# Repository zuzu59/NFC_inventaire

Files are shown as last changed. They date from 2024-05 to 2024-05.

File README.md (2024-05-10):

# NFC_inventaire
Système pour lire une puce NFC et donner des critères de qualité dans une DB API REST

zf240511.0001

**ATTENTION, documentation en cours de rédaction et le schéma n'est pas encore fait :-(  zf240510.1444**

## Buts
Système pour lire une puce NFC et donner des critères de qualité dans une DB API REST.

## Problématiques
Comme ce système va être utilisé dans une fromagerie pour inventorier des fromages dans une cave d'affinage, l'environnement est très agréssif, de l'eau salée partout et une humidité de 90%

Il faudra que le système soit totalement waterproof à la projection et que l'interface utilisateur soit avec des *boutons* capacitifs hyper simple à utiliser pour envoyer les caractéristiques des fromages dans la DB.

## Moyens
### J'ai utilisé pour ce projet
#### un esp32-c3 super mini
https://grabcad.com/library/esp32-c3-supermini-1

https://fr.aliexpress.com/item/1005006170575141.html

https://www.studiopieters.nl/esp32-c3-pinout/

https://forum.fritzing.org/t/need-esp32-c3-super-mini-board-model/20561

#### Un lecteur de puces NFC
https://www.aliexpress.com/item/1005006005040320.html

https://randomnerdtutorials.com/security-access-using-mfrc522-rfid-reader-with-arduino/

https://www.instructables.com/Using-Mifare-Ultralight-C-With-RC522-on-Arduino/

https://www.arduino.cc/reference/en/libraries/mfrc522/

https://forum.fritzing.org/uploads/default/original/2X/3/3bd6227b905a571e0d28ae941e6b9554a32d2a9a.fzpz

https://github.com/miguelbalboa/rfid/tree/master/doc/fritzing

#### Un interrupteur analogique
https://www.aliexpress.com/item/1005003404607069.html

#### Des switches capacitifs
https://www.aliexpress.com/item/1005006087171183.html

## Sources
https://forum.fritzing.org/t/need-esp32-c3-super-mini-board-model/20561

https://www.digikey.fr/fr/resources/conversion-calculators/conversion-calculator-voltage-divider

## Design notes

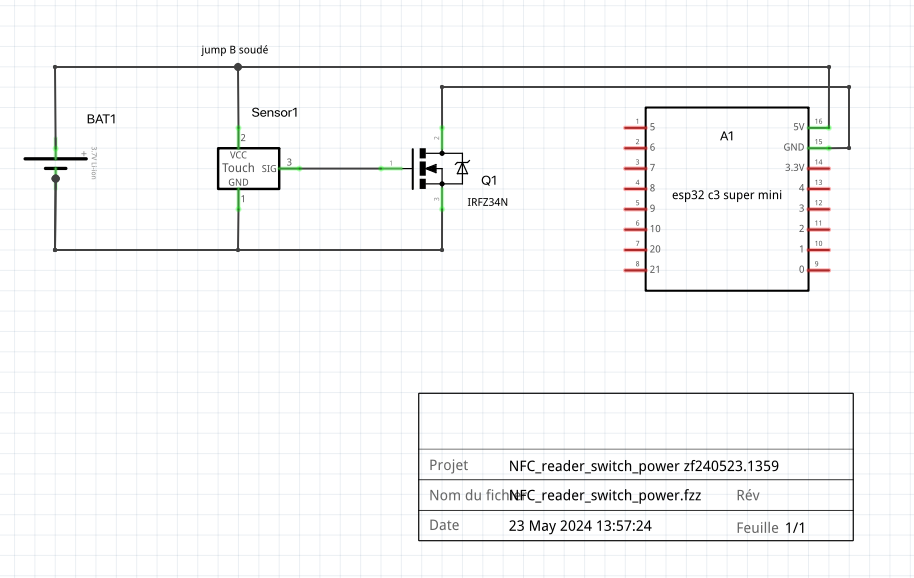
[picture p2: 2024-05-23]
schema/schema_NFC_reader_switch_power.png

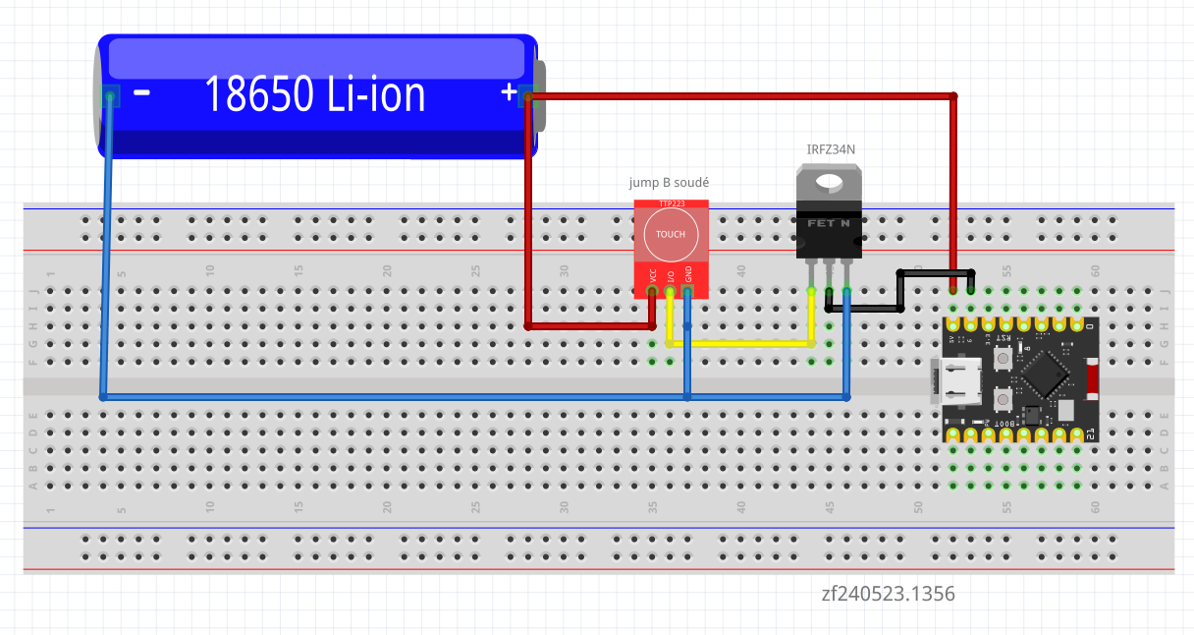
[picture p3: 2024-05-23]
schema/breadboard_NFC_reader_switch_power.png

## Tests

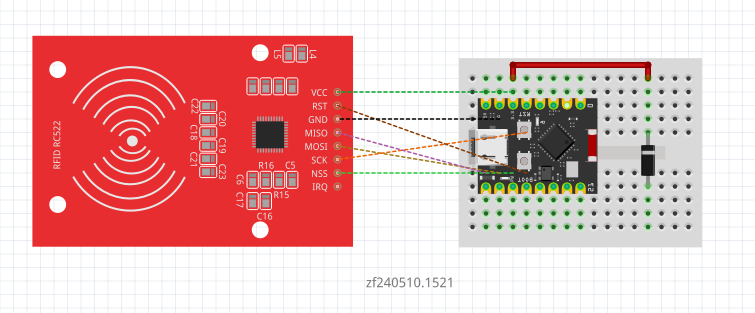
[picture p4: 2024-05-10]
schema/breadboard_NFC_reader_test1.png

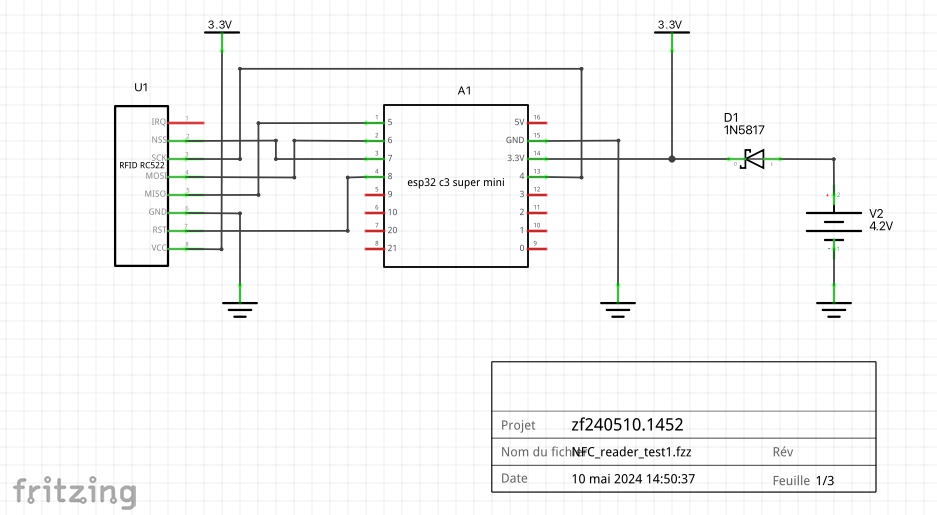
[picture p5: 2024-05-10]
schema/schema NFC_reader_test1.png

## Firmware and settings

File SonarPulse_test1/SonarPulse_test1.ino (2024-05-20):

// Petit test pour voir comment faire un sonar pulse avec la led sans bloquer la boucle loop
// ATTENTION, ce code a été écrit pour un esp32-c3 super mini. Pas testé sur les autres boards !
//
#define zVERSION "zf240520.1320"
/*
Utilisation:

Astuce:

Installation:

Pour les esp32-c3 super mini, il faut:
 * choisir comme board ESP32C3 Dev Module
 * disabled USB CDC On Boot et utiliser USBSerial. au lieu de Serial. pour la console !
 * changer le schéma de la partition à Minimal SPIFFS (1.9MB APP with OTA/190kB SPIFFS)

Pour le WiFiManager, il faut installer cette lib depuis le lib manager sur Arduino:
https://github.com/tzapu/WiFiManager

Pour le lecteur de NFC RFID RC522, il faut installer cette lib depuis le lib manager sur Arduino:
https://github.com/miguelbalboa/rfid   (elle est vieille mais fonctionne encore super bien zf240510)

Pour JSON, il faut installer cette lib:
https://github.com/bblanchon/ArduinoJson

Pour le stick LED RGB il faut installer cette lib: 
https://github.com/FastLED/FastLED    (by Daniel Garcia)

Sources:
https://randomnerdtutorials.com/security-access-using-mfrc522-rfid-reader-with-arduino/
https://forum.fritzing.org/t/need-esp32-c3-super-mini-board-model/20561
https://www.aliexpress.com/item/1005006005040320.html
https://randomnerdtutorials.com/esp32-useful-wi-fi-functions-arduino
https://dronebotworkshop.com/wifimanager/
https://github.com/FastLED/FastLED/blob/master/examples/Blink/Blink.ino
https://lastminuteengineers.com/esp32-ota-web-updater-arduino-ide/
https://chat.mistral.ai/    pour toute la partie API REST ᕗ
*/

/*
 * 
 * Pin layout used:
 * -----------------------------------------------------------------------------------------
 *             MFRC522      ESP32-c3
 *             Reader/PCB   super mini
 * Signal      Pin          Pin
 * -----------------------------------------------------------------------------------------
 * RST/Reset   RST          GPIO10
 * SPI SS      SDA(SS)      GPIO7
 * SPI MOSI    MOSI         GPIO6
 * SPI MISO    MISO         GPIO5
 * SPI SCK     SCK          GPIO4
 *
 */


// #define DEBUG true
// #undef DEBUG


// General
const int ledPin = 8;    // the number of the LED pin
const int buttonPin = 9;  // the number of the pushbutton pin
float rrsiLevel = 0;      // variable to store the RRSI level
const int zSonarPulseOn = 100;    // délai pour sonarPulse
const int zSonarPulseOff = 200;    // délai pour sonarPulse
const int zSonarPulseWait = 1000;    // délai pour sonarPulse
byte zSonarPulseState = 1;    // état pour sonarPulse
long zSonarPulseNextMillis = 0;    // état pour sonarPulse

String newRFID = "00 00 00 00 00 00 00";
String tagFromager = "";
String tagNotation = "";

bool zProcFromager = false;
bool zProcAddFromage = false;
bool zProcAddInventaire = false;
bool zProcAddTagCmd = false;
bool zProcNotation = false;

const int ledWifi               = 0;
const int ledProcFromager       = 1;
const int ledProcAddFromage     = 2;
const int ledProcAddInventaire  = 3;
const int ledProcAddTagCmd      = 4;
const int ledProcNotation       = 5;
const int ledOk                 = 6;
const int ledFree               = 7;





// WIFI
#include <WiFi.h>
#include <HTTPClient.h>
#include <WiFiManager.h>
#include "secrets.h"
WiFiClient client;
HTTPClient http;

static void ConnectWiFi() {
    WiFi.mode(WIFI_STA); //Optional    
    WiFiManager wm;
    bool res;
    res = wm.autoConnect("esp32_wifi_config",""); // password protected ap
    if(!res) {
        USBSerial.println("Failed to connect");
        // ESP.restart();
    }
    WiFi.setTxPower(WIFI_POWER_8_5dBm);  //c'est pour le Lolin esp32-c3 mini V1 ! https://www.wemos.cc/en/latest/c3/c3_mini_1_0_0.html
    int txPower = WiFi.getTxPower();
    USBSerial.print("TX power: ");
    USBSerial.println(txPower);
    USBSerial.println("Connecting");
    while(WiFi.status() != WL_CONNECTED){
        USBSerial.print(".");
        delay(100);
    }
    USBSerial.println("\nConnected to the WiFi network");
    USBSerial.print("SSID: ");
    USBSerial.println(WiFi.SSID());
    USBSerial.print("RSSI: ");
    USBSerial.println(WiFi.RSSI());
    USBSerial.print("IP: ");
    USBSerial.println(WiFi.localIP());
}


// OTA WEB server
const char* host = "esp32-c3";
#include "otaWebServer.h"


// Stick LED RGB
#include <FastLED.h>
#define NUM_LEDS 8
#define DATA_PIN 3
CRGB leds[NUM_LEDS];


// API JSON
#include <ArduinoJson.h>
const char* zToken = apiToken;
long zIndex = 0;

const char* apiGetIndexToto = apiServerName "/api/v2/tables/mccwrj43jwtogvs/records?viewId=vwwm6yz0uhytc9er&fields=Index&sort=-Index&limit=1&shuffle=0&offset=0";
const char* apiPostNewRecordToto = apiServerName "/api/v2/tables/mccwrj43jwtogvs/records";

const char* apiGetIndexTagCmd = apiServerName "/api/v2/tables/mmkk01cafw4ynyp/records?viewId=vw68oujklglmmlp3&fields=Index&sort=-Index&limit=1&shuffle=0&offset=0";
const char* apiPostNewRecordTagCmd = apiServerName "/api/v2/tables/mmkk01cafw4ynyp/records";

const char* apiGetRfidTagCmd = apiServerName "/api/v2/tables/mmkk01cafw4ynyp/records?viewId=vw68oujklglmmlp3&fields=UID%20RFID&limit=25&shuffle=0&offset=0";

const char* apiGetIndexTagLog = apiServerName "/api/v2/tables/md736jl0ppzh1jj/records?viewId=vwl66xl4gwk919f1&fields=Index&sort=-Index&limit=1&shuffle=0&offset=0";
const char* apiPostNewRecordTagLog = apiServerName "/api/v2/tables/md736jl0ppzh1jj/records";


String getToDB(String zApigetToDB) {
  // Efectue la requête GET pour récupérer l'enregistrement
  http.begin(zApigetToDB);
  http.addHeader("accept", "application/json");
  http.addHeader("xc-token", zToken);
  int httpCode = http.GET();
  if (httpCode > 0) {
    if (httpCode == HTTP_CODE_OK) {
      String payload = http.getString();
      USBSerial.println(payload);
      http.end();
      return(payload);
    } else {
      USBSerial.printf("Error on HTTP request: %d\n", httpCode);
    }
  } else {
    USBSerial.println("Error on HTTP request");
  }
  http.end();
}


void getIndex(String payload){
  // Alloue un objet DynamicJsonDocument pour stocker le JSON
  DynamicJsonDocument doc(1024);
  // Désérialise le JSON
  DeserializationError error = deserializeJson(doc, payload);
  if (error) {
    USBSerial.print("deserializeJson() failed: ");
    USBSerial.println(error.f_str());
    return;
  }
  // Récupère le champ "Index" et l'incrémente
  zIndex = doc["list"][0]["Index"].as<long>() + 1;
  USBSerial.print("Index incremented: ");
  USBSerial.println(zIndex);
}




static void postToDB(String zApiPostToDb, String jsonReqBody) {
  // Effectuer la requête POST pour créer le nouvel enregistrement
  http.begin(zApiPostToDb);
  http.addHeader("Content-Type", "application/json");
  http.addHeader("xc-token", zToken);
  int httpCode = http.POST(jsonReqBody);
  if (httpCode > 0) {
    USBSerial.printf("POST request response code: %d\n", httpCode);
    if (httpCode == HTTP_CODE_OK) {
      String response = http.getString();
      USBSerial.println("POST request response:");
      USBSerial.println(response);
    }
  } else {
    USBSerial.println("Error on POST request");
  }
  http.end();
}






// RFID MFRC522
#include <SPI.h>
#include <MFRC522.h>

#define SS_PIN 7
#define RST_PIN 10
 
MFRC522 rfid(SS_PIN, RST_PIN);  // Instance of the class
MFRC522::MIFARE_Key key; 

// Init array that will store new NUID 
byte nuidPICC[7];

// start RFID
void startRFID() {
  SPI.begin(); // Init SPI bus
  rfid.PCD_Init(); // Init MFRC522 

  for (byte i = 0; i < 6; i++) {
    key.keyByte[i] = 0xFF;
  }

  USBSerial.println("Prêt à scanner les tags NFC ᕗ");
}


// Lit un tag NFC 
int readRFID() {
  if (rfid.PICC_IsNewCardPresent()){
    USBSerial.println("Une carte est présente !");
    // Verify if the NUID has been readed
    if (rfid.PICC_ReadCardSerial()){
      // Halt PICC and Stop encryption on PCD
      rfid.PICC_HaltA(); rfid.PCD_StopCrypto1();
      // Get card type
      USBSerial.print("\n\n*****************\nCarte type: ");
      MFRC522::PICC_Type piccType = rfid.PICC_GetType(rfid.uid.sak);
      USBSerial.println(rfid.PICC_GetTypeName(piccType));
      // New UID ?
      if (rfid.uid.uidByte[0] != nuidPICC[0] || rfid.uid.uidByte[1] != nuidPICC[1] || rfid.uid.uidByte[2] != nuidPICC[2] || 
        rfid.uid.uidByte[3] != nuidPICC[3] || rfid.uid.uidByte[4] != nuidPICC[4] || rfid.uid.uidByte[5] != nuidPICC[5] || 
        rfid.uid.uidByte[6] != nuidPICC[6] ) {
        // Store NUID into nuidPICC array
        for (byte i = 0; i < 7; i++) { nuidPICC[i] = rfid.uid.uidByte[i]; }
        convHex(rfid.uid.uidByte, rfid.uid.size);
        return(1);
      } else {
        return(3);
      }
    }
  }else {
    return(0);
  }
}


// Converti l'UID en hexa dans newRFID
void convHex(byte *buffer, byte bufferSize) {
  newRFID = "";
  for (byte i = 0; i < bufferSize; i++) {
    char hexStr[3]; // Crée un tableau temporaire pour stocker la valeur hexadécimale
    sprintf(hexStr, "%02X", buffer[i]); // Convertit la valeur en hexadécimal et la stocke dans hexStr
    newRFID += hexStr; // Concatène la valeur hexadécimale à newRFID
    newRFID += " "; // Ajoute un espace après chaque octet
  }
  newRFID.trim(); // Supprime les espaces supplémentaires à la fin de la chaîne
}







void setup() {
    pinMode(ledPin, OUTPUT);
    sonarPulse();
    pinMode(buttonPin, INPUT_PULLUP);

    // start serial console
    USBSerial.begin(19200);
    USBSerial.setDebugOutput(true);       //pour voir les messages de debug des libs sur la console série !
    delay(3000);                          //le temps de passer sur la Serial Monitor ;-)
    USBSerial.println("\n\n\n\n**************************************\nCa commence !");
    USBSerial.println(zVERSION);

    // si le bouton FLASH de l'esp32-c3 est appuyé dans les 3 secondes après le boot, la config WIFI sera effacée !
    if ( digitalRead(buttonPin) == LOW) {
      WiFiManager wm;    
      wm.resetSettings();
      USBSerial.println("Config WIFI effacée !"); delay(1000);
      ESP.restart();
    }

    // start LED RGB
    FastLED.addLeds<NEOPIXEL, DATA_PIN>(leds, NUM_LEDS);  // GRB ordering is assumed

    // start WIFI
    leds[ledWifi] = CRGB::Blue; FastLED.show();
    digitalWrite(ledPin, HIGH);
    USBSerial.println("Connect WIFI !");
    ConnectWiFi();
    leds[ledWifi] = CRGB::Green; FastLED.show();
    digitalWrite(ledPin, LOW);
    delay(200); 

    // start OTA server
    otaWebServer();

    // leds[6] = CRGB::Blue; FastLED.show();
    // USBSerial.println("Et en avant pour la connexion à la DB !");
    // USBSerial.print("\nAvec comme apiGetIndex: ");
    // USBSerial.println(apiGetIndex);
    // USBSerial.print("et comme apiPostNewRecord: ");
    // USBSerial.println(apiPostNewRecord);

    // // start API REST
    // sendToDB("C'est le boot il n'y a pas de TAG !", zVERSION);
    // digitalWrite(ledPin, HIGH); delay(200); digitalWrite(ledPin, LOW); delay(200);
    // digitalWrite(ledPin, HIGH); delay(200); digitalWrite(ledPin, LOW); delay(200);
    // digitalWrite(ledPin, HIGH); delay(200); digitalWrite(ledPin, LOW); delay(200);
    // leds[6] = CRGB::Green; FastLED.show();
    // delay(3000); 
    // leds[6] = CRGB::Black; FastLED.show();

    // // start RFID
    // startRFID();

}


void loop() {
  // OTA loop
  server.handleClient();

  // // Lit un tag NFC 
  // leds[ledProcAddFromage] = CRGB::Blue; FastLED.show();
  // int statRFID(readRFID());
  // // USBSerial.println(statRFID);
  // if (statRFID == 1) {
  //   leds[ledProcAddFromage] = CRGB::Green; FastLED.show();
  //   USBSerial.println("Une nouvelle carte est détectée !");
  //   USBSerial.print("L'UID de la carte est: ");
  //   USBSerial.println(newRFID);
  //   procTagLog();
  //   delay(300);
  //   leds[ledProcAddFromage] = CRGB::Blue; FastLED.show();
  // } else if (statRFID == 3) {
  //   leds[ledProcAddFromage] = CRGB::Orange; FastLED.show();
  //   USBSerial.println("Carte déjà lue !");
  //   delay(300);
  //   leds[ledProcAddFromage] = CRGB::Blue; FastLED.show();
  // }


  sonarPulse();
}


void clearAllProcedures(){
  zProcFromager = false;
  zProcAddFromage = false;
  zProcAddInventaire = false;
  zProcAddTagCmd = false;
  zProcNotation = false;
}



void procFromager(){
  USBSerial.println("C'est la procédure procFromager !");
  leds[ledProcFromager] = CRGB::Green; FastLED.show();
  delay(300);
  leds[ledProcFromager] = CRGB::Black; FastLED.show();
}

void procAddFromage(){
  USBSerial.println("C'est la procédure procAddFromage !");
  leds[ledProcAddFromage] = CRGB::Green; FastLED.show();
  delay(300);
  leds[ledProcAddFromage] = CRGB::Black; FastLED.show();
}

void procAddInventaire(){
  USBSerial.println("C'est la procédure procAddInventaire !");
  leds[ledProcAddInventaire] = CRGB::Green; FastLED.show();
  delay(300);
  leds[ledProcAddInventaire] = CRGB::Black; FastLED.show();
}

void procAddTagCmd(){
  USBSerial.println("C'est la procédure procAddTagCmd !");
  leds[ledProcAddTagCmd] = CRGB::Green; FastLED.show();
  delay(300);
  leds[ledProcAddTagCmd] = CRGB::Black; FastLED.show();
}

void procNotation(){
  USBSerial.println("C'est la procédure procNotation !");
  leds[ledProcNotation] = CRGB::Green; FastLED.show();
  delay(300);
  leds[ledProcNotation] = CRGB::Black; FastLED.show();
}

void procTagLog(){
  USBSerial.println("C'est la procédure procTagLog !");

  
  getIndex(getToDB(apiGetIndexTagLog));

  // Créer le corps de la requête POST
  StaticJsonDocument<1024> reqBody;
  reqBody["Index"] = zIndex;
  reqBody["UID RFID"] = newRFID;
  reqBody["Comment"] = zVERSION;
  reqBody["SSID"] = WiFi.SSID();
  reqBody["RSSI"] = WiFi.RSSI();
  reqBody["IP"] = WiFi.localIP();
  String jsonReqBody;
  serializeJson(reqBody, jsonReqBody);

  // Post la requête à la DB
  postToDB(apiPostNewRecordTagLog, jsonReqBody);

  leds[ledOk] = CRGB::Green; FastLED.show();
  delay(300);
  leds[ledOk] = CRGB::Black; FastLED.show();
}


// const int zSonarPulseOn = 25;    // délai pour sonarPulse
// const int zSonarPulseOff = 50;    // délai pour sonarPulse
// const int zSonarPulseWait = 200;    // délai pour sonarPulse
// byte zSonarPulseState = 1;    // état pour sonarPulse 1=allumé On, 2= éteint Off, 3= allumé On, 4= éteint Wait
// long zSonarPulseNextMillis = 0;    // état pour sonarPulse


// Machine à état pour faire pulser deux fois la petite LED sans bloquer le système
void sonarPulse(){
  if (zSonarPulseNextMillis < millis()){
    switch (zSonarPulseState){
      // 1ère pulse allumée que l'on doit éteindre !
      case 1:
        digitalWrite(ledPin, HIGH);
        zSonarPulseNextMillis = millis() + zSonarPulseOff;
        zSonarPulseState = 2;
        break;
      // 1ère pulse éteinte que l'on doit allumer !
      case 2:
        digitalWrite(ledPin, LOW);
        zSonarPulseNextMillis = millis() + zSonarPulseOn;
        zSonarPulseState = 3;
        break;
      // 2e pulse allumée que l'on doit éteindre et attendre le wait !
      case 3:
        digitalWrite(ledPin, HIGH);
        zSonarPulseNextMillis = millis() + zSonarPulseWait;
        zSonarPulseState = 4;
        break;
      // 2e pulse éteinte pendant le wait que l'on doit allumer !
      case 4:
        digitalWrite(ledPin, LOW);
        zSonarPulseNextMillis = millis() + zSonarPulseOn;
        zSonarPulseState = 1;
        break;
    }
  }
}

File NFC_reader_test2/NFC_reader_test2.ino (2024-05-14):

// Tests pour lire l'UID sur une carte NFC avec le lecteur RFID RC522
// ATTENTION, ce code a été écrit pour un esp32-c3 super mini. Pas testé sur les autres boards !
//
#define zVERSION "zf240512.1619"

//
// Utilisation:
//
// Astuce:
//
// Installation:
// 
// Il faut disabled USB CDC On Boot et utiliser USBSerial. au lieu de Serial. pour la console !
//
// Pour le lecteur de NFC RFID RC522, il faut installer cette lib depuis le lib manager sur Arduino:
// https://github.com/miguelbalboa/rfid   (elle est vieille mais fonctionne encore très bien zf240510)
//
// Pour le analog buttons il faut installer ces lib: 
//https://github.com/rlogiacco/AnalogButtons
//
// Sources:
// https://randomnerdtutorials.com/security-access-using-mfrc522-rfid-reader-with-arduino/
// https://forum.fritzing.org/t/need-esp32-c3-super-mini-board-model/20561
// https://www.aliexpress.com/item/1005006005040320.html
// https://randomnerdtutorials.com/esp32-useful-wi-fi-functions-arduino
//
/*
 * 
 * Pin layout used:
 * -----------------------------------------------------------------------------------------
 *             MFRC522      ESP32-c3
 *             Reader/PCB   super mini
 * Signal      Pin          Pin
 * -----------------------------------------------------------------------------------------
 * RST/Reset   RST          GPIO10   ATTENTION changé de 8 à 10 le 240512.1616, car au de la LED BUILTIN
 * SPI SS      SDA(SS)      GPIO7
 * SPI MOSI    MOSI         GPIO6
 * SPI MISO    MISO         GPIO5
 * SPI SCK     SCK          GPIO4
 *
 */


// #define DEBUG true
// #undef DEBUG


// General
const int ledPin = 8;    // the number of the LED pin
//
// ATTENTION, il faudra changer la pin RST pour le lecteur RFID RC522 car elle est utilisée par la led builting zf240512.1246
//
const int buttonPin = 9;  // the number of the pushbutton pin


// RFID MFRC522
#include <SPI.h>
#include <MFRC522.h>

#define SS_PIN 7
#define RST_PIN 10               // ATTENTION changé de 8 à 9 le 240512.1616, car au de la LED BUILTIN
 
MFRC522 rfid(SS_PIN, RST_PIN);  // Instance of the class
MFRC522::MIFARE_Key key; 

// Init array that will store new NUID 
byte nuidPICC[4];


// Helper routine to dump a byte array as hex values to Serial. 
void printHex(byte *buffer, byte bufferSize) {
    for (byte i = 0; i < bufferSize; i++) {
      USBSerial.print(buffer[i] < 0x10 ? " 0" : " ");
      USBSerial.print(buffer[i], HEX);
    }
}


// Helper routine to dump a byte array as dec values to Serial.
void printDec(byte *buffer, byte bufferSize) {
    for (byte i = 0; i < bufferSize; i++) {
      USBSerial.print(' ');
      USBSerial.print(buffer[i], DEC);
    }
}


void setup() { 
    pinMode(ledPin, OUTPUT);
    digitalWrite(ledPin, HIGH); delay(200); digitalWrite(ledPin, LOW); delay(200);
    digitalWrite(ledPin, HIGH); delay(200); digitalWrite(ledPin, LOW); delay(200);


    USBSerial.begin(19200);
    USBSerial.setDebugOutput(true);       //pour voir les messages de debug des libs sur la console série !
    delay(3000);  //le temps de passer sur la Serial Monitor ;-)
    USBSerial.println("\n\n\n\n**************************************\nCa commence !\n");

    SPI.begin(); // Init SPI bus
    rfid.PCD_Init(); // Init MFRC522 

    for (byte i = 0; i < 6; i++) {
      key.keyByte[i] = 0xFF;
    }

    USBSerial.println(F("This code scan ALL MIFARE UID ᕗ"));
    USBSerial.print(F("Using the following key:"));
    printHex(key.keyByte, MFRC522::MF_KEY_SIZE);
}
 
void loop() {

    // Reset the loop if no new card present on the sensor/reader. This saves the entire process when idle.
    if ( ! rfid.PICC_IsNewCardPresent())
      return;

    // Verify if the NUID has been readed
    if ( ! rfid.PICC_ReadCardSerial())
      return;

    digitalWrite(ledPin, HIGH); delay(200); digitalWrite(ledPin, LOW); delay(200);
    digitalWrite(ledPin, HIGH); delay(200); digitalWrite(ledPin, LOW); delay(200);
    digitalWrite(ledPin, HIGH); delay(200); digitalWrite(ledPin, LOW); delay(200);

    USBSerial.print(F("\n\n*****************\nPICC type: "));
    MFRC522::PICC_Type piccType = rfid.PICC_GetType(rfid.uid.sak);
    USBSerial.println(rfid.PICC_GetTypeName(piccType));



    if (rfid.uid.uidByte[0] != nuidPICC[0] || 
      rfid.uid.uidByte[1] != nuidPICC[1] || 
      rfid.uid.uidByte[2] != nuidPICC[2] || 
      rfid.uid.uidByte[3] != nuidPICC[3] ) {
      USBSerial.println(F("A new card has been detected."));

      // Store NUID into nuidPICC array
      for (byte i = 0; i < 4; i++) {
        nuidPICC[i] = rfid.uid.uidByte[i];
      }
    
      USBSerial.println(F("The NUID tag is:"));
      USBSerial.print(F("In hex: "));
      printHex(rfid.uid.uidByte, rfid.uid.size);
      USBSerial.println();
      USBSerial.print(F("In dec: "));
      printDec(rfid.uid.uidByte, rfid.uid.size);
      USBSerial.println();
    }
    else USBSerial.println(F("Card read previously."));

    // Halt PICC
    rfid.PICC_HaltA();

    // Stop encryption on PCD
    rfid.PCD_StopCrypto1();
}

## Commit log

2024-05-10 new: YEAH, on dirait que je suis capable de lire l'UID d'une carte NFC NTAG215 presque du 1er coup \o/
    [thermo-int-mqtt-dsleep.fzz]
2024-05-10 new: fait enfin le schéma de câblage du RFID RC522 reader. Très important car il n'est pas facile (5 câbles)
    [NFC_reader_test1.fzz]
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2024-05-11 new: commencé de faire des tests pour accéder à une API REST sur NocoDB. YEAH, cela fonctionne du 1er coup \o/ Merci à Mistral.ai ;-)
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2024-05-11 change: je demande le plus grand (dernier) Index dans la table \o/
2024-05-12 new: ajouté la récupération du champ Index de la DB et incrémenté de 1
2024-05-12 new: et voilà maintenant la requête API REST POST qui fonctionne \o/
2024-05-12 refact: refactorisé la partie location schéma pour le projet
    [NFC_reader_test1.fzz]
2024-05-12 new: commencé à refactorisé la partie API REST pour la normaliser boîte à outils pour l'utilisation future avec le NFC reader
    [NFC_reader_test1.fzz]
2024-05-12 refact: continué la refactorisation du code pour l'API REST. Ce n'est pas terminé !
2024-05-12 refact: Voilà, terminé de mettre au propre toute la partie API REST, maintenant on va pouvoir s'attaquer au code du lecteur de TAG RFID
2024-05-12 new: commencé à tester la lecture simplifiée d'UID de TAG NFC. Pas terminé !
2024-05-13 new: je teste l'OTA sur esp32-c3 et cela fonctionne super bien \o/ Bon il y a encore pas mal de refactorisation de code pour cacher la merde au chat ;-)
2024-05-13 refact: pas mal refactorisé la partie OTA, cela fonctionne super bien. Me reste encore à épurer quelques trucs et après on pourra partir en prod avec ce nouvel outil \o/
2024-05-13 new: voilà mon projet RFID reader a maintenant l'OTA \o/ C'est quand même plus pratique pour le dev ᕗ
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2024-05-14 refact: bien épuré encore le code, cela commence à devenir très propre. Complèté aussi la partie auto-documentation au début du code
2024-05-14 new: je sauve maintenant aussi l'adresse IP dans la DB NocoDB. Pratique pour connaître l'adresse IP quand il faudra flasher via OTA à distance
2024-05-14 change: recâblé dans le bon sens le stick de LEDS RB, maintenant la 1ère est bien la 0 et plus la 7 !
2024-05-14 new: intégré la partie lecteur RFID dans le code. Cela fonctionne bien, mais c'est encore lent, il faudra que je refactorise la loop
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2024-05-14 change: j'essaie de convertir l'UID du TAG dans une variable en hexa mais je n'y suis pas arrivé :-(
2024-05-14 wip: cela commence enfin à fonctionner comme je le veux. Il faut que je purge encore le code de debug
2024-05-14 new: voilà, super, j'arrive à pousser dans la DB l'UID du tag NFC lu \o/
2024-05-16 new: Commencé à écrire le logigramme pour la logique de traitement des TAG lus
2024-05-16 new: ajouté la fonctionalité wifi manager pour pouvoir configurer le wifi quand il n'y a pas le wifi habituel. Plus besoin donc de reflasher l'esp quand on change de wifi
2024-05-16 new: ajouté la possibilité d'effacer la configuration WIFI si on maintient le bouton flash appuyé dans les 3 secondes au boot ᕗ
2024-05-17 refact: je refactorise complètement la partie lecture de UID de tag NFC. Pas encore terminé !
2024-05-17 wip: la refactorisation de la partie RFID avance mais n'est pas encore terminée !
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2024-05-18 refact: refactorisé les requêtes API REST pour les rendre génériques. Problème encore avec l'UID du TAG lu qui est toujours le même !
2024-05-18 refact: refactorisé la partie getIndex pour rendre la fonction getToDB plus générique. Ainsi je peux récupérer facilement n'importe quel champ maintenant
2024-05-20 new: voilà ma machine à états pour faire pulser deux fois la petite led sans delai est terminée et est fonctionnelle \o/
2024-05-20 new: mis en prod la machine d'états pour le sonar pulse, c'est vraiment mieux maintenant pour lire les tag RFID \o/
2024-05-20 change: mis une machine à état dans la boucle loop, c'est plus propre
2024-05-20 wip: commence à rechercher un tag dans la table tag cmd pour voir si c'est un tag cmd ?
2024-05-20 wip: j'ai encore des problèmes avec getToDB, j'ai l'âge du capitaine, c'est n'importe quoi
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2024-05-20 wip: YEAH, j'ai enfin trouvé cette erreur à la con, il manquait juste un return("erreur") après l'erreur afin que la fonction revient bien avec un string. Je sauve ici pour pouvoir revenir en arrière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
2024-05-20 wip: complètement refactorisé la fonction getToDb, maintenant c'est beacoup plus propre et ne par plus en boucle quand il y a une erreur dans l'url
2024-05-20 new: je reconnais les tag cmd fromager et addtagcmd, mais c'est loin d'être encore fonctionnel !
2024-05-21 refact: complètement refactorisé et simplifié la procédure traitement des tags. Ne fonctionne pas encore !
2024-05-21 refact: refactorisation du traitement des tags cmd terminée. Cela fonctionne maintenant et c'est nettement plus lisible \o/
2024-05-23 new: ajouté le schéma de câblage pour le MOSTFET avec le petit switch capacitif pour l'alimentation du circuit
    [NFC_reader_switch_power.fzz]
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2024-06-10 fix: corrigé le problème de non lecture des tags. C'était bien le problème de la loop qui avait un délais de 60 secondes :-(
    [NFC_reader_API_test2.ino]
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2024-06-11 new: ajouté une procédure pour le reboot avec un tag procReboot \o/
    [NFC_reader_API_test2.ino]
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
